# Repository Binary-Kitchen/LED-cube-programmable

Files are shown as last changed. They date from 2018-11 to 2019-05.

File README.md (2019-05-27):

# Programmable LED Cube
A 4x4x4 LED Cube which can be programmed with an arduino nano. A harder soldering challenge combining SMD soldering with very fragile LEDs.

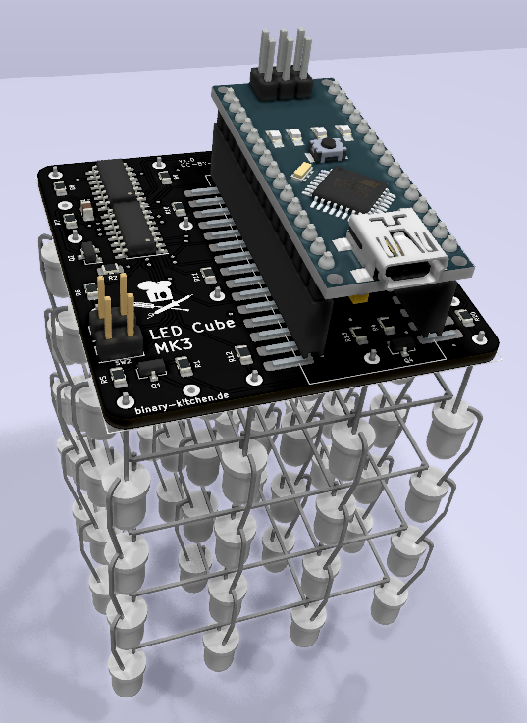
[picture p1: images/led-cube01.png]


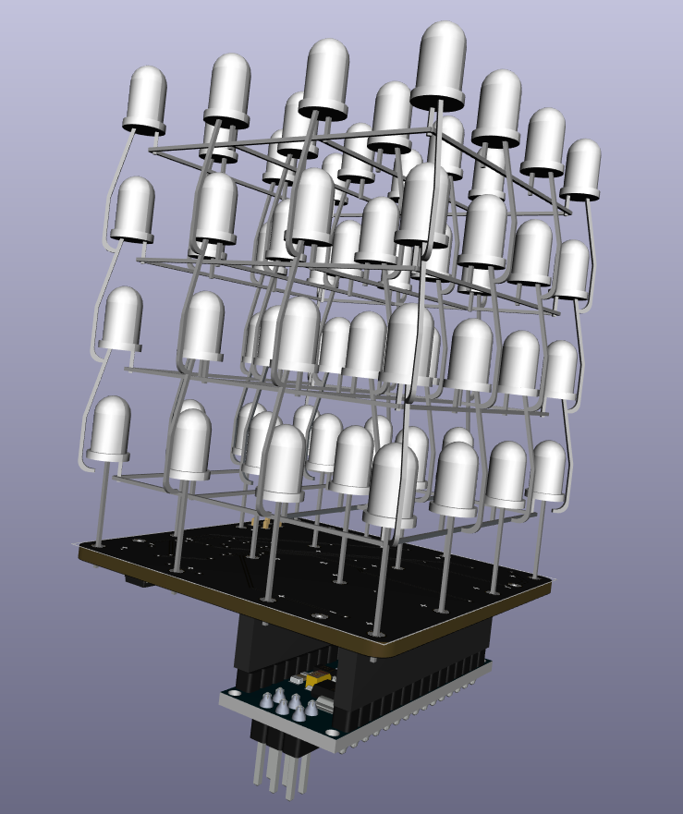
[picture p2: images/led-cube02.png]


## Bill of Material
| Item | Qty | Footprint |
|---|-----|---|
| Arduino Nano v3 | 1 | ---- |
| Ceramic Capacitor 100 nF | 1 | 0805 |
| Mosfet 2N7002 | 4 | SOT23 |
| Resistor 1 kOhm | 4 |  0805 |
| Resistor 52 Ohm | 16  | 0805 |
| Shiftregister 74HC595 | 2 | SOIC-16 3.9x9.9 mm |
| 5mm LED | 64  | ---- |

## Manual
TBD

## Copyright and Authorship
- Idea/PCB-Layout: [CC-BY-SA 4.0](https://creativecommons.org/licenses/by-sa/4.0/) - [Thomas Schmid and Timo Schindler](https://www.binary-kitchen.de)
- Manual (TeX): [LPPL](https://www.latex-project.org/lppl.txt) - [Marei Peischl](https://peitex.de)
- Manual (pdf): [CC-BY-SA 4.0](https://creativecommons.org/licenses/by-sa/4.0/) - [Binary Kitchen e.V.](https://www.binary-kitchen.de)

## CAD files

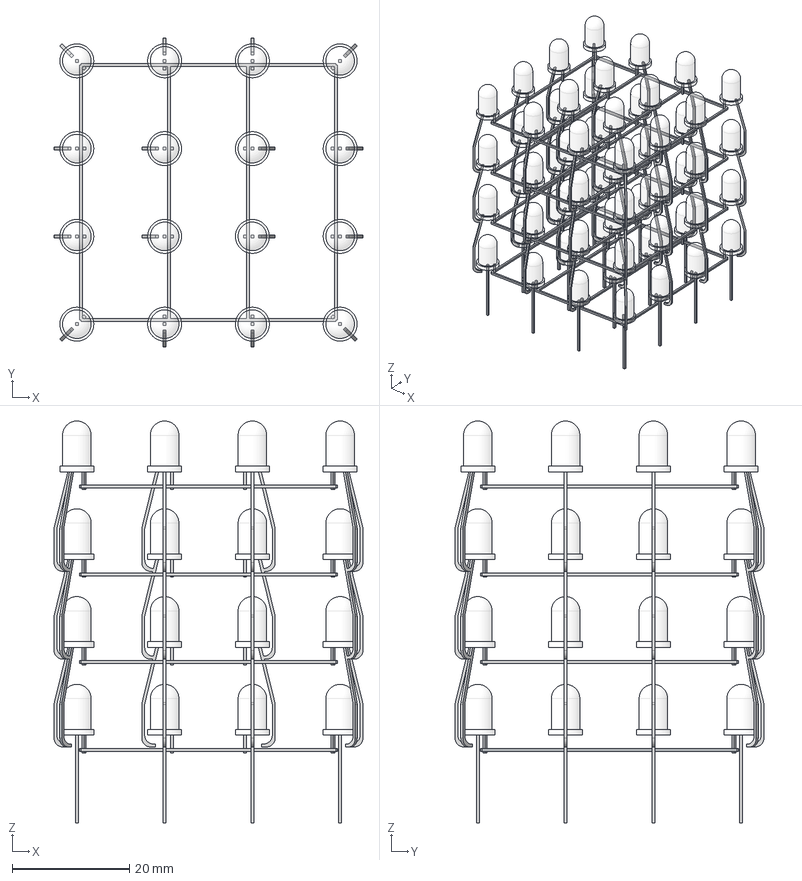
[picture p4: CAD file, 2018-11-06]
3dmodels/leds.stp
52.8 x 52.8 x 68.7 mm

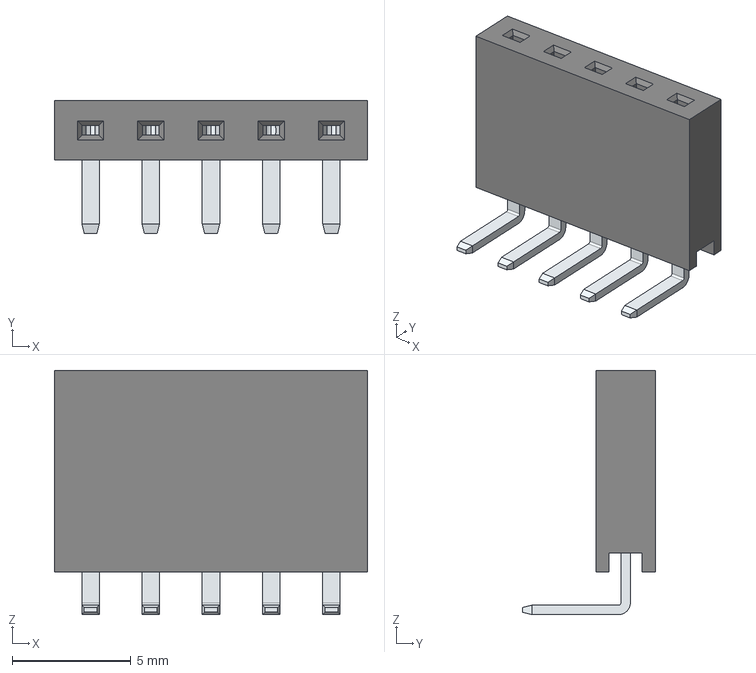
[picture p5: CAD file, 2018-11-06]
3dmodels/613005143121 (rev1).stp
13.2 x 5.59 x 10.3 mm
6130xx143121_PIN x 5

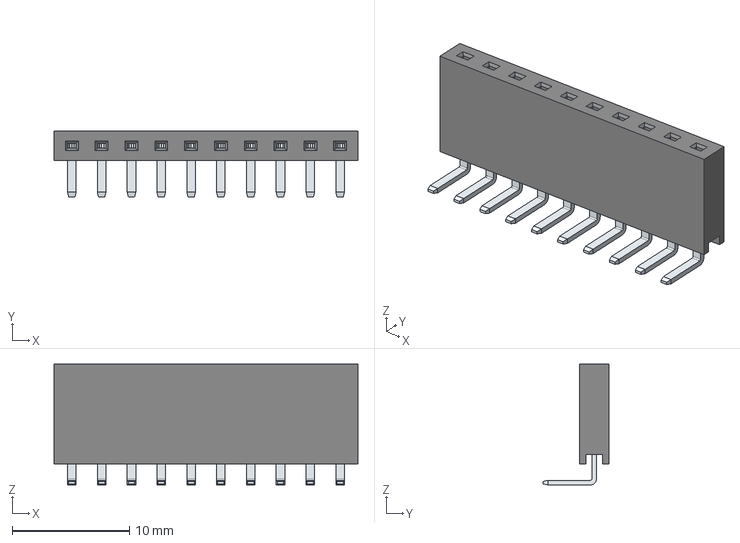
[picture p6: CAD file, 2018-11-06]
3dmodels/613010143121 (rev1).stp
25.9 x 5.59 x 10.3 mm
6130xx143121_PIN x 10

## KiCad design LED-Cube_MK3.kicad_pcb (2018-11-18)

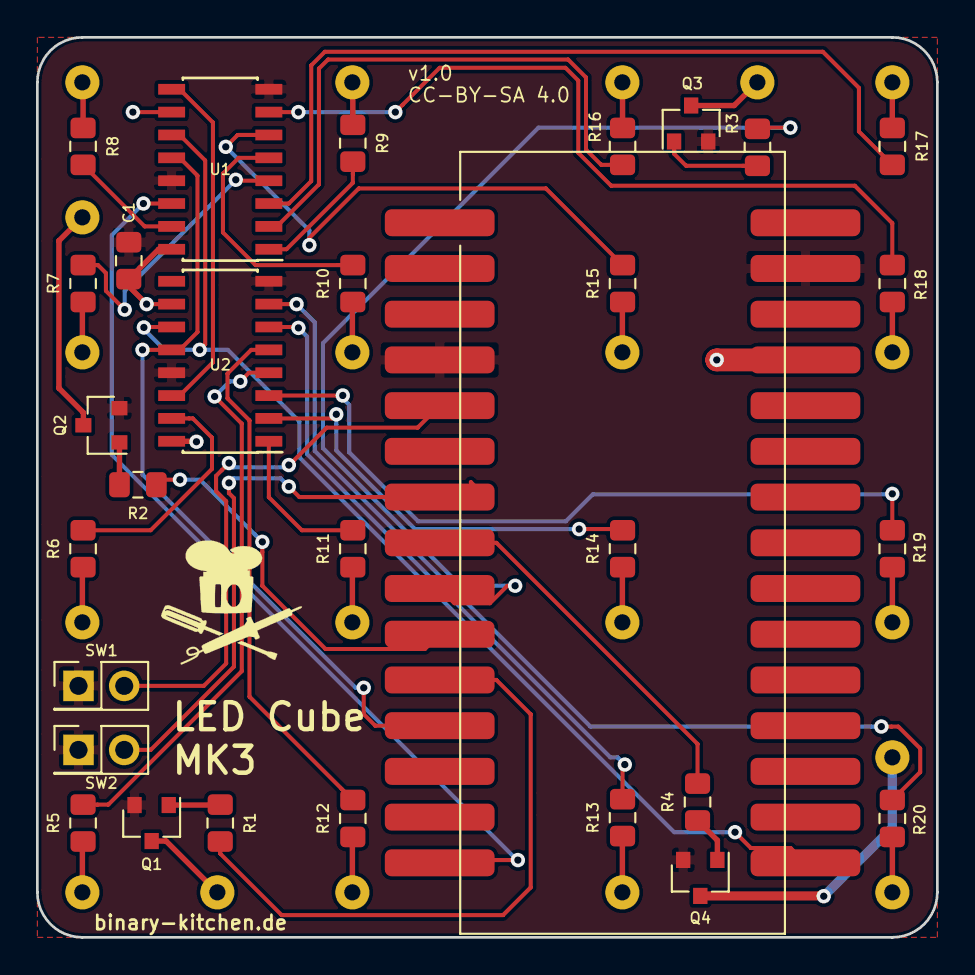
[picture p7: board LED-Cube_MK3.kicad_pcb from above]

Board: 2 copper layers, 50.0 x 50.0 mm, 31 parts (1 on the bottom side), 52 nets.

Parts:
A1: Arduino_Nano_v3.x; Arduino_Nano_SMD
C1: C; C_0805_2012Metric_Pad1.15x1.40mm_HandSolder
Q1, Q2, Q3, Q4: 2N7002; SOT-23
R1, R2, R3, R4, R5, R6, R7, R8, R9, R10, R11, R12, R13, R14, R15, R16, R17, R18, R19, R20: R; R_0805_2012Metric_Pad1.15x1.40mm_HandSolder
SW1, SW2: SW_Push; PinHeader_2x01_P2.54mm_Vertical
U1, U2: 74HC595; SOIC-16_3.9x9.9mm_P1.27mm
U3: LED_Cube_5mm_4x4x4

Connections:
+5V: A1.27, C1.1, U1.10, U1.16, U2.10, U2.16
/QH*: U1.9, U2.14
/cathode1_enable: A1.8, R4.2
/cathode2_enable: A1.9, R3.2
/cathode3_enable: A1.10, R2.2
/cathode4_enable: A1.11, R1.2
/mode_sw: A1.7, SW2.2
/mosi: A1.15, U1.14
/power_sw: A1.5, SW1.2
/scrclk: A1.16, U1.11, U2.11
/sr_latch: A1.12, U1.12, U2.12
GND: A1.4, A1.29, C1.2, Q1.2, Q2.2, Q3.2, Q4.2, SW1.1, SW2.1, U1.8, U1.13, U2.8, U2.13
LED_1: R8.2, U1.15
LED_2: R9.2, U1.1
LED_3: R16.2, U1.2
LED_4: R17.2, U1.3
LED_5: R7.2, U1.4
LED_6: R10.2, U1.5
LED_7: R15.2, U1.6
LED_8: R18.2, U1.7
LED_9: R6.2, U2.15
LED_10: R11.2, U2.1
LED_11: R14.2, U2.2
LED_12: R19.2, U2.3
LED_13: R5.2, U2.4
LED_14: R12.2, U2.5
LED_15: R13.2, U2.6
LED_16: R20.2, U2.7
unnamed: Q1.1, R1.1
unnamed: Q1.3, U3.17
unnamed: Q2.1, R2.1
unnamed: Q2.3, U3.18
unnamed: Q3.1, R3.1
unnamed: Q3.3, U3.19
unnamed: Q4.1, R4.1
unnamed: Q4.3, U3.20
unnamed: R5.1, U3.1
unnamed: R6.1, U3.2
unnamed: R7.1, U3.3
unnamed: R8.1, U3.4
unnamed: R9.1, U3.5
unnamed: R10.1, U3.6
unnamed: R11.1, U3.7
unnamed: R12.1, U3.8
unnamed: R13.1, U3.9
unnamed: R14.1, U3.10
unnamed: R15.1, U3.11
unnamed: R16.1, U3.12
unnamed: R17.1, U3.13
unnamed: R18.1, U3.14
unnamed: R19.1, U3.15
unnamed: R20.1, U3.16

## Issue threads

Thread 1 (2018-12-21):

Cube driver class does not work when compiled with arduino IDE

rckTom, 2018-12-21:
The driver class cube_4 does not work properly when compiled with the arduino IDE. Compiling with the provided makefile results in a working executable.

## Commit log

2018-11-05 inital commit
    [LED-Cube_MK3.kicad_pcb, LED-Cube_MK3.sch, _saved_LED-Cube_MK3.sch]
2018-11-06 change led spacing to 15mm and add arduino 3d model
    [613005143121 (rev1).stp, 613010143121 (rev1).stp, LED-Cube_MK3.kicad_pcb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]
2018-11-06 add 3d model of leds
    [LED-Cube_MK3.kicad_pcb, leds.stp]
2018-11-18 added svg and kitchen-head for printing on board
2018-11-18 added footprint
2018-11-18 added logo, copyright, name and version
    [LED-Cube_MK3.kicad_pcb]
2018-11-18 minor changes
    [LED-Cube_MK3.kicad_pcb]
2018-11-18 added gerber files
    [LED-Cube_MK3-B.Cu.gbr, LED-Cube_MK3-B.Mask.gbr, LED-Cube_MK3-B.SilkS.gbr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]
2018-12-18 Add missing part values
    [LED-Cube_MK3.sch]
2018-12-21 add first working prototype of firmware
2018-12-21 add bill of material to readme
